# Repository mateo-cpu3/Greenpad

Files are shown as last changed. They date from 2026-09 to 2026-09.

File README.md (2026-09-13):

# Kyle's GREEN Macropad

---

It's special because it's green nothing else. this is my first macropad or engineering project in general so its not perfect, but I did spend a lot of time figuring everything out especially since I wanted it to be 3 x 3 not just 3 keys. 

---

# Challenges 

literally everything I had to restart because I didn't know you had to space the keys 19.05mm and ended messing everything up because I couldn't figure out why it didn't align with the case I also found the fusion interface super confusing, my mouse wheel broke halfway so zooming in and out was a pain

---



---

# BOM

* 9x Cherry MX switches
* 1x XIAO RP2040
* 4x M3 Heatset inserts
* M3 screws
* M3 Hex Nuts
* 9x 1N4148 diodes

---

# Schematic 
 
 

# PCB

 

# Case



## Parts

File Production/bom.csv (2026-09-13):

Reference | Qty | Value | DNP | Footprint | Datasheet | #
D1,D2,D3,D4,D5,D6,D7,D8,D9 | 9 | 1N4148 Diodes |  | Diode_THT:D_DO-35_SOD27_P7.62mm_Horizontal |  | 1
S1,S2,S3,S4,S5,S6,S7,S8,S9 | 9 | SW_Cherry_MX_1.00u_PCB |  | Button_Switch_Keyboard:SW_Cherry_MX_1.00u_PCB |  | 2
U1 | 1 | Seeed_XIAO_RP2040 |  | footprints:XIAO-Generic-Hybrid-14P-2.54-21X17.8MM |  | 3

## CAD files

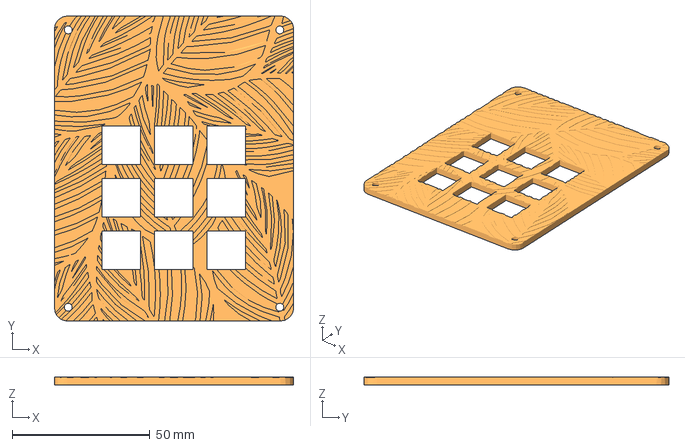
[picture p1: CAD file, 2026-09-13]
Production/topcase.step
86.7 x 110.5 x 3.00 mm

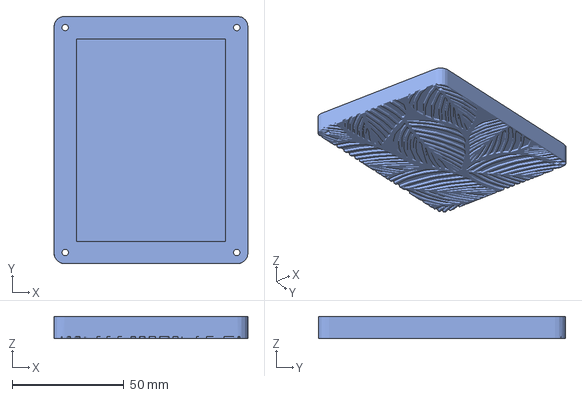
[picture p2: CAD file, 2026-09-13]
Production/bottomcase.step
86.7 x 110.5 x 10.0 mm

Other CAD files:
CAD/fullassembly.3mf

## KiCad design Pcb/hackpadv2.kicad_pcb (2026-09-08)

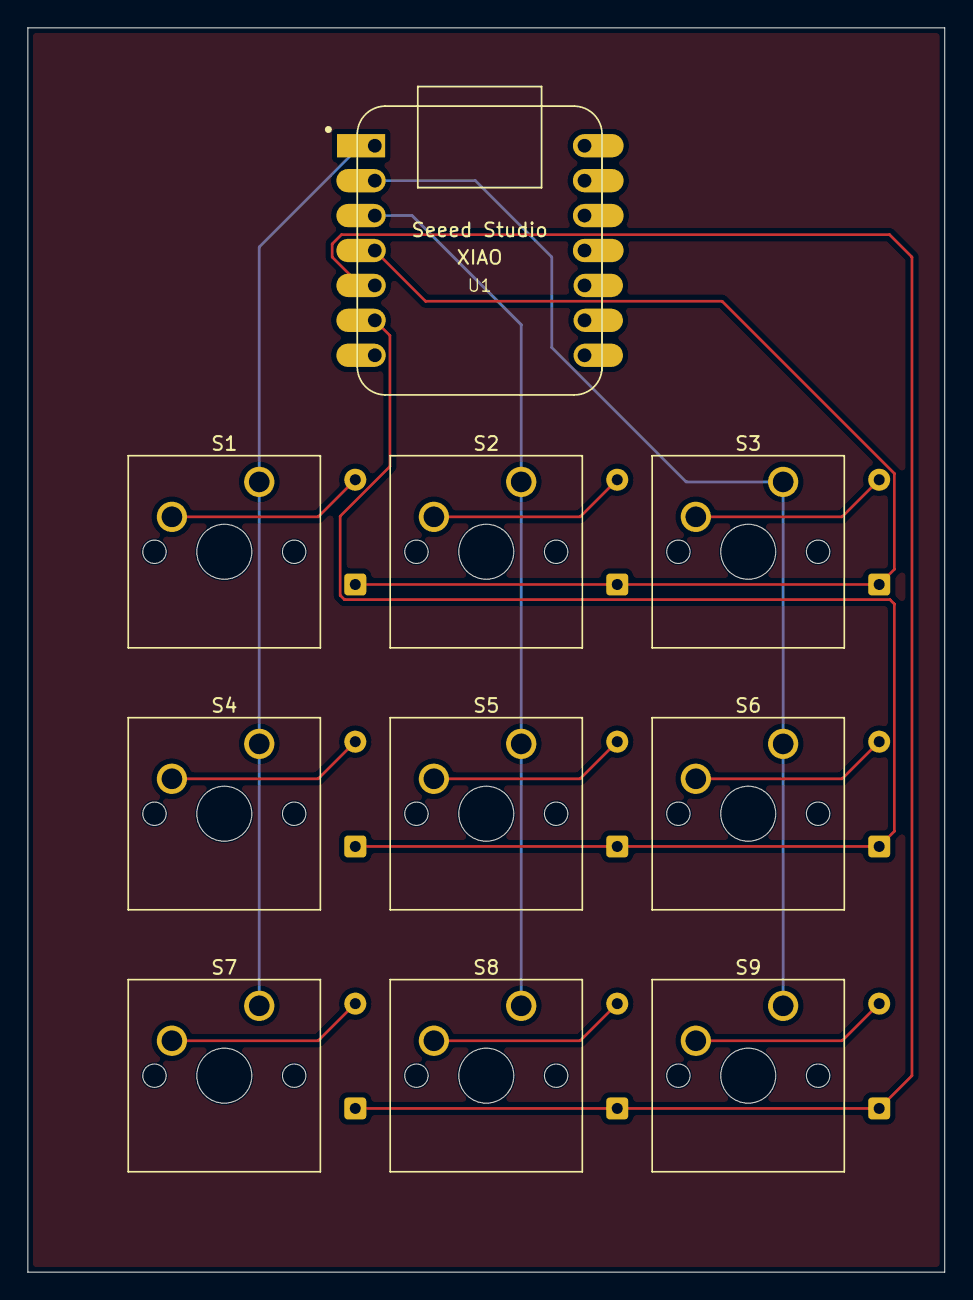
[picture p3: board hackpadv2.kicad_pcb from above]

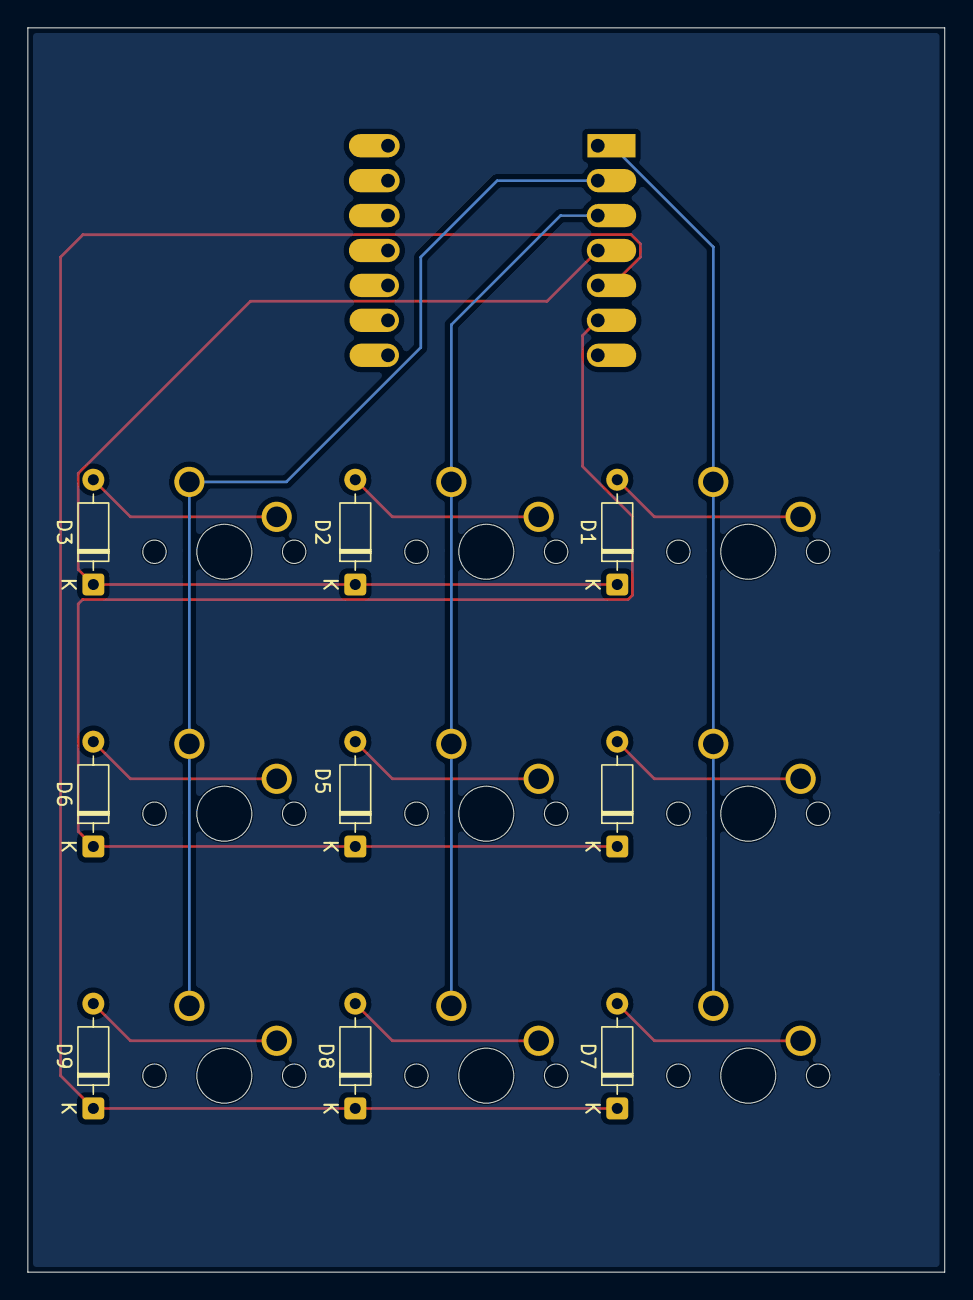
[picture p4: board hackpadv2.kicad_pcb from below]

Board: 2 copper layers, 66.7 x 90.5 mm, 19 parts (9 on the bottom side), 15 nets.

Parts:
D1, D2, D3, D4, D5, D6, D7, D8, D9: D_DO-35_SOD27_P7.62mm_Horizontal
S1, S2, S3, S4, S5, S6, S7, S8, S9: SW_Cherry_MX_1.00u_PCB
U1: MOUDLE-SEEEDUINO-XIAO; XIAO-Generic-Hybrid-14P-2.54-21X17.8MM

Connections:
Column 0: S1.1, S4.1, S7.1, U1.1 (PA02_A0_D0)
Column 1: S2.1, S5.1, S8.1, U1.3 (PA10_A2_D2)
Column 2: S3.1, S6.1, S9.1, U1.2 (PA4_A1_D1)
unnamed: D1.2 (A), S1.2
unnamed: D2.2 (A), S2.2
unnamed: D3.2 (A), S3.2
unnamed: D4.2 (A), S4.2
unnamed: D5.2 (A), S5.2
unnamed: D6.2 (A), S6.2
unnamed: D7.2 (A), S7.2
unnamed: D8.2 (A), S8.2
unnamed: D9.2 (A), S9.2
row 0: D1.1 (K), D2.1 (K), D3.1 (K), U1.4 (PA11_A3_D3)
row 1: D4.1 (K), D5.1 (K), D6.1 (K), U1.6 (PA9_A5_D5_SCL)
row 2: D7.1 (K), D8.1 (K), D9.1 (K), U1.5 (PA8_A4_D4_SDA)
